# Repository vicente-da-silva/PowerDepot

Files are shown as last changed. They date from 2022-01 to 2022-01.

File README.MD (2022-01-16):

# Power Depot FJ Overland Build
## V1.0
The project started out with the goal of building a simple drawer system for my FJ. That simple goal turned into this Power Depot project! I may decide to split this project into 2 in the future as the Power Depot electronics evolve but for now the electrical and drawer system is presented as a single project.
Check out the detailed assembly document PowerDepotV1.pdf
It should be possible to easily create designs for other vehicles using the parts designed in this project.


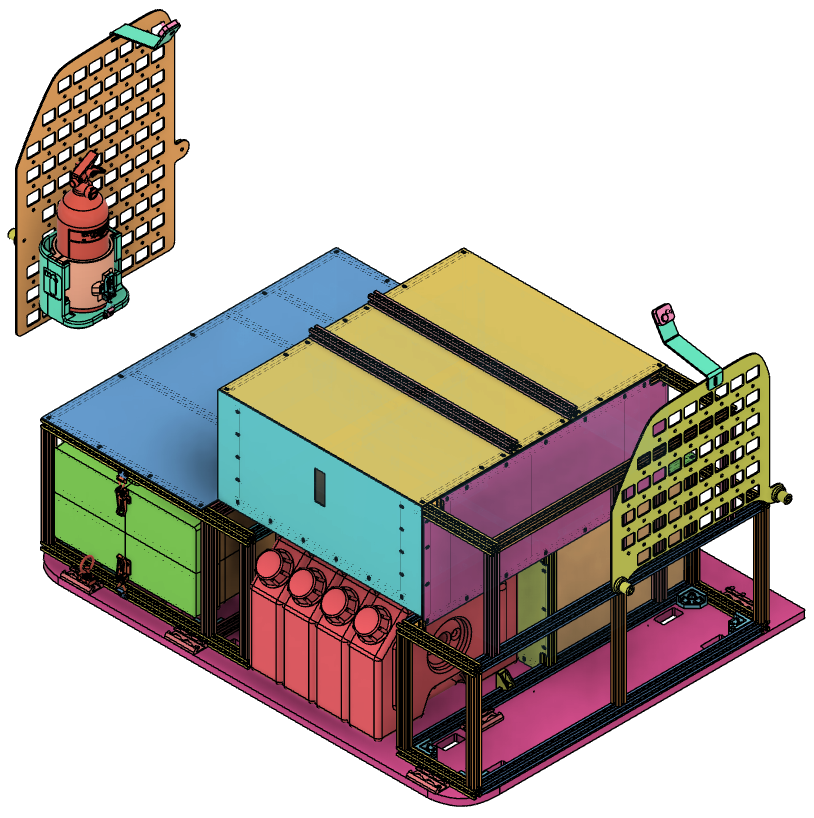
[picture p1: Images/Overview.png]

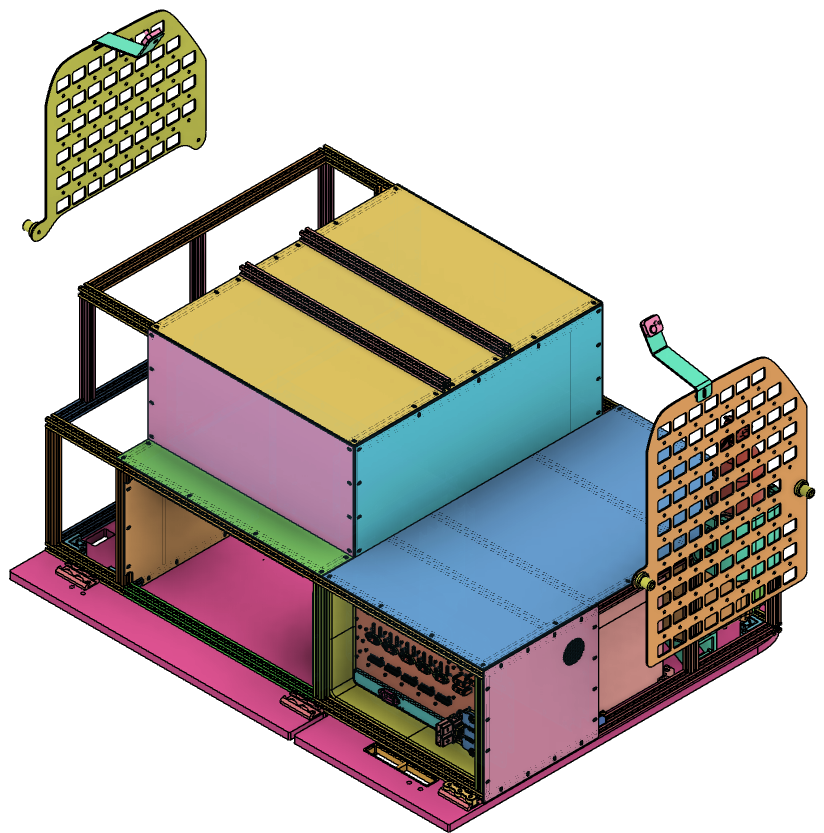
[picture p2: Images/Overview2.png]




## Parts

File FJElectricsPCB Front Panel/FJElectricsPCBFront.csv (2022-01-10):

Source: | C:\Users\vicen\OneDrive\Documents\Data\Code\FJElectricsPCB Front Panel\FJElectricsPCBFront.sch
Date: | 2021/04/24 10:04:37 AM
Tool: | Eeschema (5.1.8)-1
Generator: | C:\Program Files\KiCad\bin\scripting\plugins/bom_csv_grouped_by_value.py
Component Count: | 90
Individual Components:
Item | Qty | Reference(s) | Value | LibPart | Footprint | Datasheet
 |  | Fuse1 | LED | Device:LED | LED_THT:LED_D5.0mm | ~
 |  | Fuse2 | LED | Device:LED | LED_THT:LED_D5.0mm | ~
 |  | Fuse3 | LED | Device:LED | LED_THT:LED_D5.0mm | ~
 |  | Fuse4 | LED | Device:LED | LED_THT:LED_D5.0mm | ~
 |  | Fuse5 | LED | Device:LED | LED_THT:LED_D5.0mm | ~
 |  | Fuse6 | LED | Device:LED | LED_THT:LED_D5.0mm | ~
 |  | Fuse7 | LED | Device:LED | LED_THT:LED_D5.0mm | ~
 |  | Fuse8 | LED | Device:LED | LED_THT:LED_D5.0mm | ~
 |  | Fuse9 | LED | Device:LED | LED_THT:LED_D5.0mm | ~
 |  | Fuse10 | LED | Device:LED | LED_THT:LED_D5.0mm | ~
 |  | Fuse_1 | 30A | Device:Fuse | FJElectricsPCBCommon:FuseHolder20x5Fuse | ~
 |  | Fuse_2 | 30A | Device:Fuse | FJElectricsPCBCommon:FuseHolder20x5Fuse | ~
 |  | Fuse_3 | 30A | Device:Fuse | FJElectricsPCBCommon:FuseHolder20x5Fuse | ~
 |  | Fuse_4 | 30A | Device:Fuse | FJElectricsPCBCommon:FuseHolder20x5Fuse | ~
 |  | Fuse_5 | 30A | Device:Fuse | FJElectricsPCBCommon:FuseHolder20x5Fuse | ~
 |  | Fuse_6 | 30A | Device:Fuse | FJElectricsPCBCommon:FuseHolder20x5Fuse | ~
 |  | Fuse_7 | 30A | Device:Fuse | FJElectricsPCBCommon:FuseHolder20x5Fuse | ~
 |  | Fuse_8 | 30A | Device:Fuse | FJElectricsPCBCommon:FuseHolder20x5Fuse | ~
 |  | Fuse_9 | 30A | Device:Fuse | FJElectricsPCBCommon:FuseHolder20x5Fuse | ~
 |  | Fuse_10 | 30A | Device:Fuse | FJElectricsPCBCommon:FuseHolder20x5Fuse | ~
 |  | H1 | MountingHole | Mechanical:MountingHole | FJElectricsPCBCommon:NPTH_3mm_ID | ~
 |  | H3 | MountingHole | Mechanical:MountingHole | FJElectricsPCBCommon:NPTH_3mm_ID | ~
 |  | H4 | MountingHole | Mechanical:MountingHole | FJElectricsPCBCommon:NPTH_3mm_ID | ~
 |  | H6 | MountingHole | Mechanical:MountingHole | FJElectricsPCBCommon:NPTH_3mm_ID | ~
 |  | H7 | MountingHole | Mechanical:MountingHole | FJElectricsPCBCommon:NPTH_3mm_ID | ~
 |  | H10 | MountingHole | Mechanical:MountingHole | FJElectricsPCBCommon:NPTH_3mm_ID | ~
 |  | H11 | MountingHole | Mechanical:MountingHole | FJElectricsPCBCommon:NPTH_3mm_ID | ~
 |  | H12 | MountingHole | Mechanical:MountingHole | FJElectricsPCBCommon:NPTH_3mm_ID | ~
 |  | H14 | MountingHole | Mechanical:MountingHole | FJElectricsPCBCommon:NPTH_3mm_ID | ~
 |  | H15 | MountingHole | Mechanical:MountingHole | FJElectricsPCBCommon:NPTH_3mm_ID | ~
 |  | H16 | MountingHole | Mechanical:MountingHole | FJElectricsPCBCommon:NPTH_3mm_ID | ~
 |  | H21 | MountingHole | Mechanical:MountingHole | FJElectricsPCBCommon:NPTH_3mm_ID | ~
 |  | H23 | MountingHole | Mechanical:MountingHole | FJElectricsPCBCommon:NPTH_3mm_ID | ~
 |  | H24 | MountingHole | Mechanical:MountingHole | FJElectricsPCBCommon:NPTH_3mm_ID | ~
 |  | H26 | MountingHole | Mechanical:MountingHole | FJElectricsPCBCommon:NPTH_3mm_ID | ~
 |  | H27 | MountingHole | Mechanical:MountingHole | FJElectricsPCBCommon:NPTH_3mm_ID | ~
 |  | H29 | MountingHole | Mechanical:MountingHole | FJElectricsPCBCommon:NPTH_3mm_ID | ~
 |  | H31 | MountingHole | Mechanical:MountingHole | FJElectricsPCBCommon:NPTH_3mm_ID | ~
 |  | H33 | MountingHole | Mechanical:MountingHole | FJElectricsPCBCommon:NPTH_3mm_ID | ~
 |  | H34 | MountingHole | Mechanical:MountingHole | FJElectricsPCBCommon:NPTH_3mm_ID | ~
 |  | H36 | MountingHole | Mechanical:MountingHole | FJElectricsPCBCommon:NPTH_3mm_ID | ~
 |  | J3 | MEDIUM TB x2 | Connector_Generic:Conn_01x02 | FJElectricsPCBCommon:TerminalBlock_7.62_2x1 | ~
 |  | J4 | MEDIUM TB x2 | Connector_Generic:Conn_01x02 | FJElectricsPCBCommon:TerminalBlock_7.62_2x1 | ~
 |  | J6 | MEDIUM TB x2 | Connector_Generic:Conn_01x02 | FJElectricsPCBCommon:TerminalBlock_7.62_2x1 | ~
 |  | J8 | MEDIUM TB x2 | Connector_Generic:Conn_01x02 | FJElectricsPCBCommon:TerminalBlock_7.62_2x1 | ~
 |  | J9 | MEDIUM TB x2 | Connector_Generic:Conn_01x02 | FJElectricsPCBCommon:TerminalBlock_7.62_2x1 | ~
 |  | J14 | MEDIUM TB x2 | Connector_Generic:Conn_01x02 | FJElectricsPCBCommon:TerminalBlock_7.62_2x1 | ~
 |  | J15 | PP 2 WAY | Connector_Generic:Conn_01x02 | FJElectricsPCBCommon:PowerPole_15_45 | ~
 |  | J16 | PP 2 WAY | Connector_Generic:Conn_01x02 | FJElectricsPCBCommon:PowerPole_15_45 | ~
 |  | J17 | MEDIUM TB x2 | Connector_Generic:Conn_01x02 | FJElectricsPCBCommon:TerminalBlock_7.62_2x1 | ~
 |  | J18 | Conn_01x01 | Connector_Generic:Conn_01x01 | FJElectricsPCBCommon:TerminalM20_x1 | ~
 |  | J19 | PP 2 WAY | Connector_Generic:Conn_01x02 | FJElectricsPCBCommon:PowerPole_15_45 | ~
 |  | J20 | MEDIUM TB x2 | Connector_Generic:Conn_01x02 | FJElectricsPCBCommon:TerminalBlock_7.62_2x1 | ~
 |  | J22 | PP 2 WAY | Connector_Generic:Conn_01x02 | FJElectricsPCBCommon:PowerPole_15_45 | ~
 |  | J24 | MEDIUM TB x2 | Connector_Generic:Conn_01x02 | FJElectricsPCBCommon:TerminalBlock_7.62_2x1 | ~
 |  | J25 | PP 2 WAY | Connector_Generic:Conn_01x02 | FJElectricsPCBCommon:PowerPole_15_45 | ~
 |  | J26 | MEDIUM TB x2 | Connector_Generic:Conn_01x02 | FJElectricsPCBCommon:TerminalBlock_7.62_2x1 | ~
 |  | J27 | MEDIUM TB x2 | Connector_Generic:Conn_01x02 | FJElectricsPCBCommon:TerminalBlock_7.62_2x1 | ~
 |  | J28 | PP 2 WAY | Connector_Generic:Conn_01x02 | FJElectricsPCBCommon:PowerPole_15_45 | ~
 |  | J29 | PP 2 WAY | Connector_Generic:Conn_01x02 | FJElectricsPCBCommon:PowerPole_15_45 | ~
 |  | J30 | PP 2 WAY | Connector_Generic:Conn_01x02 | FJElectricsPCBCommon:PowerPole_15_45 | ~
 |  | J31 | PP 2 WAY | Connector_Generic:Conn_01x02 | FJElectricsPCBCommon:PowerPole_15_45 | ~
 |  | J32 | Jumper_Bolt | FJPCBComponentsCommon:Jumper_Bolt | FJElectricsPCBCommon:ScrewM4Jumper
 |  | J33 | Jumper_Bolt | FJPCBComponentsCommon:Jumper_Bolt | FJElectricsPCBCommon:ScrewM4Jumper
 |  | J34 | Jumper_Bolt | FJPCBComponentsCommon:Jumper_Bolt | FJElectricsPCBCommon:ScrewM4Jumper
 |  | J35 | PP 2 WAY | Connector_Generic:Conn_01x02 | FJElectricsPCBCommon:PowerPole_15_45 | ~
 |  | J36 | PP 2 WAY | Connector_Generic:Conn_01x02 | FJElectricsPCBCommon:PowerPole_15_45 | ~
 |  | J37 | Jumper_Bolt | FJPCBComponentsCommon:Jumper_Bolt | FJElectricsPCBCommon:ScrewM4Jumper
 |  | J38 | Jumper_Bolt | FJPCBComponentsCommon:Jumper_Bolt | FJElectricsPCBCommon:ScrewM4Jumper
 |  | J39 | Conn_01x01 | Connector_Generic:Conn_01x01 | FJElectricsPCBCommon:TerminalM20_x1 | ~
 |  | K1 | CB1-R-12V | FJPCBComponentsCommon:CB1-R-12V | FJElectricsPCBCommon:MINI_ISO_RELAY_SOCKET | https://www.panasonic-electric-works.com/pew/es/downloads/ds_dw_hl_en.pdf
 |  | K2 | CB1-R-12V | FJPCBComponentsCommon:CB1-R-12V | FJElectricsPCBCommon:MINI_ISO_RELAY_SOCKET | https://www.panasonic-electric-works.com/pew/es/downloads/ds_dw_hl_en.pdf
 |  | K3 | CB1-R-12V | FJPCBComponentsCommon:CB1-R-12V | FJElectricsPCBCommon:MINI_ISO_RELAY_SOCKET | https://www.panasonic-electric-works.com/pew/es/downloads/ds_dw_hl_en.pdf
 |  | K4 | CB1-R-12V | FJPCBComponentsCommon:CB1-R-12V | FJElectricsPCBCommon:MINI_ISO_RELAY_SOCKET | https://www.panasonic-electric-works.com/pew/es/downloads/ds_dw_hl_en.pdf
 |  | K5 | CB1-R-12V | FJPCBComponentsCommon:CB1-R-12V | FJElectricsPCBCommon:MINI_ISO_RELAY_SOCKET | https://www.panasonic-electric-works.com/pew/es/downloads/ds_dw_hl_en.pdf
 |  | R1 | 600 | Device:R_US | Resistor_THT:R_Axial_DIN0207_L6.3mm_D2.5mm_P10.16mm_Horizontal | ~
 |  | R2 | 600 | Device:R_US | Resistor_THT:R_Axial_DIN0207_L6.3mm_D2.5mm_P10.16mm_Horizontal | ~
 |  | R3 | 600 | Device:R_US | Resistor_THT:R_Axial_DIN0207_L6.3mm_D2.5mm_P10.16mm_Horizontal | ~
 |  | R4 | 600 | Device:R_US | Resistor_THT:R_Axial_DIN0207_L6.3mm_D2.5mm_P10.16mm_Horizontal | ~
 |  | R5 | 600 | Device:R_US | Resistor_THT:R_Axial_DIN0207_L6.3mm_D2.5mm_P10.16mm_Horizontal | ~
 |  | R6 | 600 | Device:R_US | Resistor_THT:R_Axial_DIN0207_L6.3mm_D2.5mm_P10.16mm_Horizontal | ~
 |  | R7 | 600 | Device:R_US | Resistor_THT:R_Axial_DIN0207_L6.3mm_D2.5mm_P10.16mm_Horizontal | ~
 |  | R8 | 600 | Device:R_US | Resistor_THT:R_Axial_DIN0207_L6.3mm_D2.5mm_P10.16mm_Horizontal | ~
 |  | R9 | 600 | Device:R_US | Resistor_THT:R_Axial_DIN0207_L6.3mm_D2.5mm_P10.16mm_Horizontal | ~
 |  | R10 | 600 | Device:R_US | Resistor_THT:R_Axial_DIN0207_L6.3mm_D2.5mm_P10.16mm_Horizontal | ~
 |  | SW1 | SW_SPST | Switch:SW_SPST | FJElectricsPCBCommon:SwitchMount | ~
 |  | SW2 | SW_SPST | Switch:SW_SPST | FJElectricsPCBCommon:SwitchMount | ~
 |  | SW3 | SW_SPST | Switch:SW_SPST | FJElectricsPCBCommon:SwitchMount | ~
 |  | SW4 | SW_SPST | Switch:SW_SPST | FJElectricsPCBCommon:SwitchMount | ~
 |  | SW5 | SW_SPST | Switch:SW_SPST | FJElectricsPCBCommon:SwitchMount | ~
Collated Components:
Item | Qty | Reference(s) | Value | LibPart | Footprint | Datasheet
1 | 10 | Fuse1, Fuse2, Fuse3, Fuse4, Fuse5, Fuse6, Fuse7, Fuse8, Fuse9, Fuse10 | LED | Device:LED | LED_THT:LED_D5.0mm | ~
2 | 10 | Fuse_1, Fuse_2, Fuse_3, Fuse_4, Fuse_5, Fuse_6, Fuse_7, Fuse_8, Fuse_9, Fuse_10 | 30A | Device:Fuse | FJElectricsPCBCommon:FuseHolder20x5Fuse | ~
3 | 21 | H1, H3, H4, H6, H7, H10, H11, H12, H14, H15, H16, H21, H23, H24, H26, H27, H29, H31, H33, H34, H36 | MountingHole | Mechanical:MountingHole | FJElectricsPCBCommon:NPTH_3mm_ID | ~
4 | 11 | J3, J4, J6, J8, J9, J14, J17, J20, J24, J26, J27 | MEDIUM TB x2 | Connector_Generic:Conn_01x02 | FJElectricsPCBCommon:TerminalBlock_7.62_2x1 | ~
5 | 11 | J15, J16, J19, J22, J25, J28, J29, J30, J31, J35, J36 | PP 2 WAY | Connector_Generic:Conn_01x02 | FJElectricsPCBCommon:PowerPole_15_45 | ~
6 | 2 | J18, J39 | Conn_01x01 | Connector_Generic:Conn_01x01 | FJElectricsPCBCommon:TerminalM20_x1 | ~
7 | 5 | J32, J33, J34, J37, J38 | Jumper_Bolt | FJPCBComponentsCommon:Jumper_Bolt | FJElectricsPCBCommon:ScrewM4Jumper
8 | 5 | K1, K2, K3, K4, K5 | CB1-R-12V | FJPCBComponentsCommon:CB1-R-12V | FJElectricsPCBCommon:MINI_ISO_RELAY_SOCKET | https://www.panasonic-electric-works.com/pew/es/downloads/ds_dw_hl_en.pdf
9 | 10 | R1, R2, R3, R4, R5, R6, R7, R8, R9, R10 | 600 | Device:R_US | Resistor_THT:R_Axial_DIN0207_L6.3mm_D2.5mm_P10.16mm_Horizontal | ~
10 | 5 | SW1, SW2, SW3, SW4, SW5 | SW_SPST | Switch:SW_SPST | FJElectricsPCBCommon:SwitchMount | ~

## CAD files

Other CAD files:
FJElectricsPCB Back Panel/FJElectricsPCBBack.step
FJElectricsPCB Front Panel/FJElectricsPCBFront.step
FJMechanical/FJDrawerExtrusionV2 v261.step
FJElectricsPCB Common/3d packages/M10 hole in a M20 95 Lug.step
FJElectricsPCB Common/3d packages/SB 120.step
FJElectricsPCB Common/3d packages/SB 50.step
FJElectricsPCB Common/3d packages/TerminalMount.step
FJElectricsPCB Common/3d packages/MegaFuse.step
FJElectricsPCB Common/3d packages/Maxi Fuse.step
FJElectricsPCB Common/3d packages/PCB Fuse Reguar Mount.step
FJElectricsPCB Common/3d packages/RegularFuse.step
FJElectricsPCB Common/3d packages/2-1904045-4 Relay Conn.step
FJElectricsPCB Common/3d packages/RelaySocket.step
FJElectricsPCB Common/3d packages/TB005-762-02P_Black - S.step
FJElectricsPCB Common/3d packages/MegaMount.step
FJElectricsPCB Common/3d packages/PCB Fuse Maxi Mount.step
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

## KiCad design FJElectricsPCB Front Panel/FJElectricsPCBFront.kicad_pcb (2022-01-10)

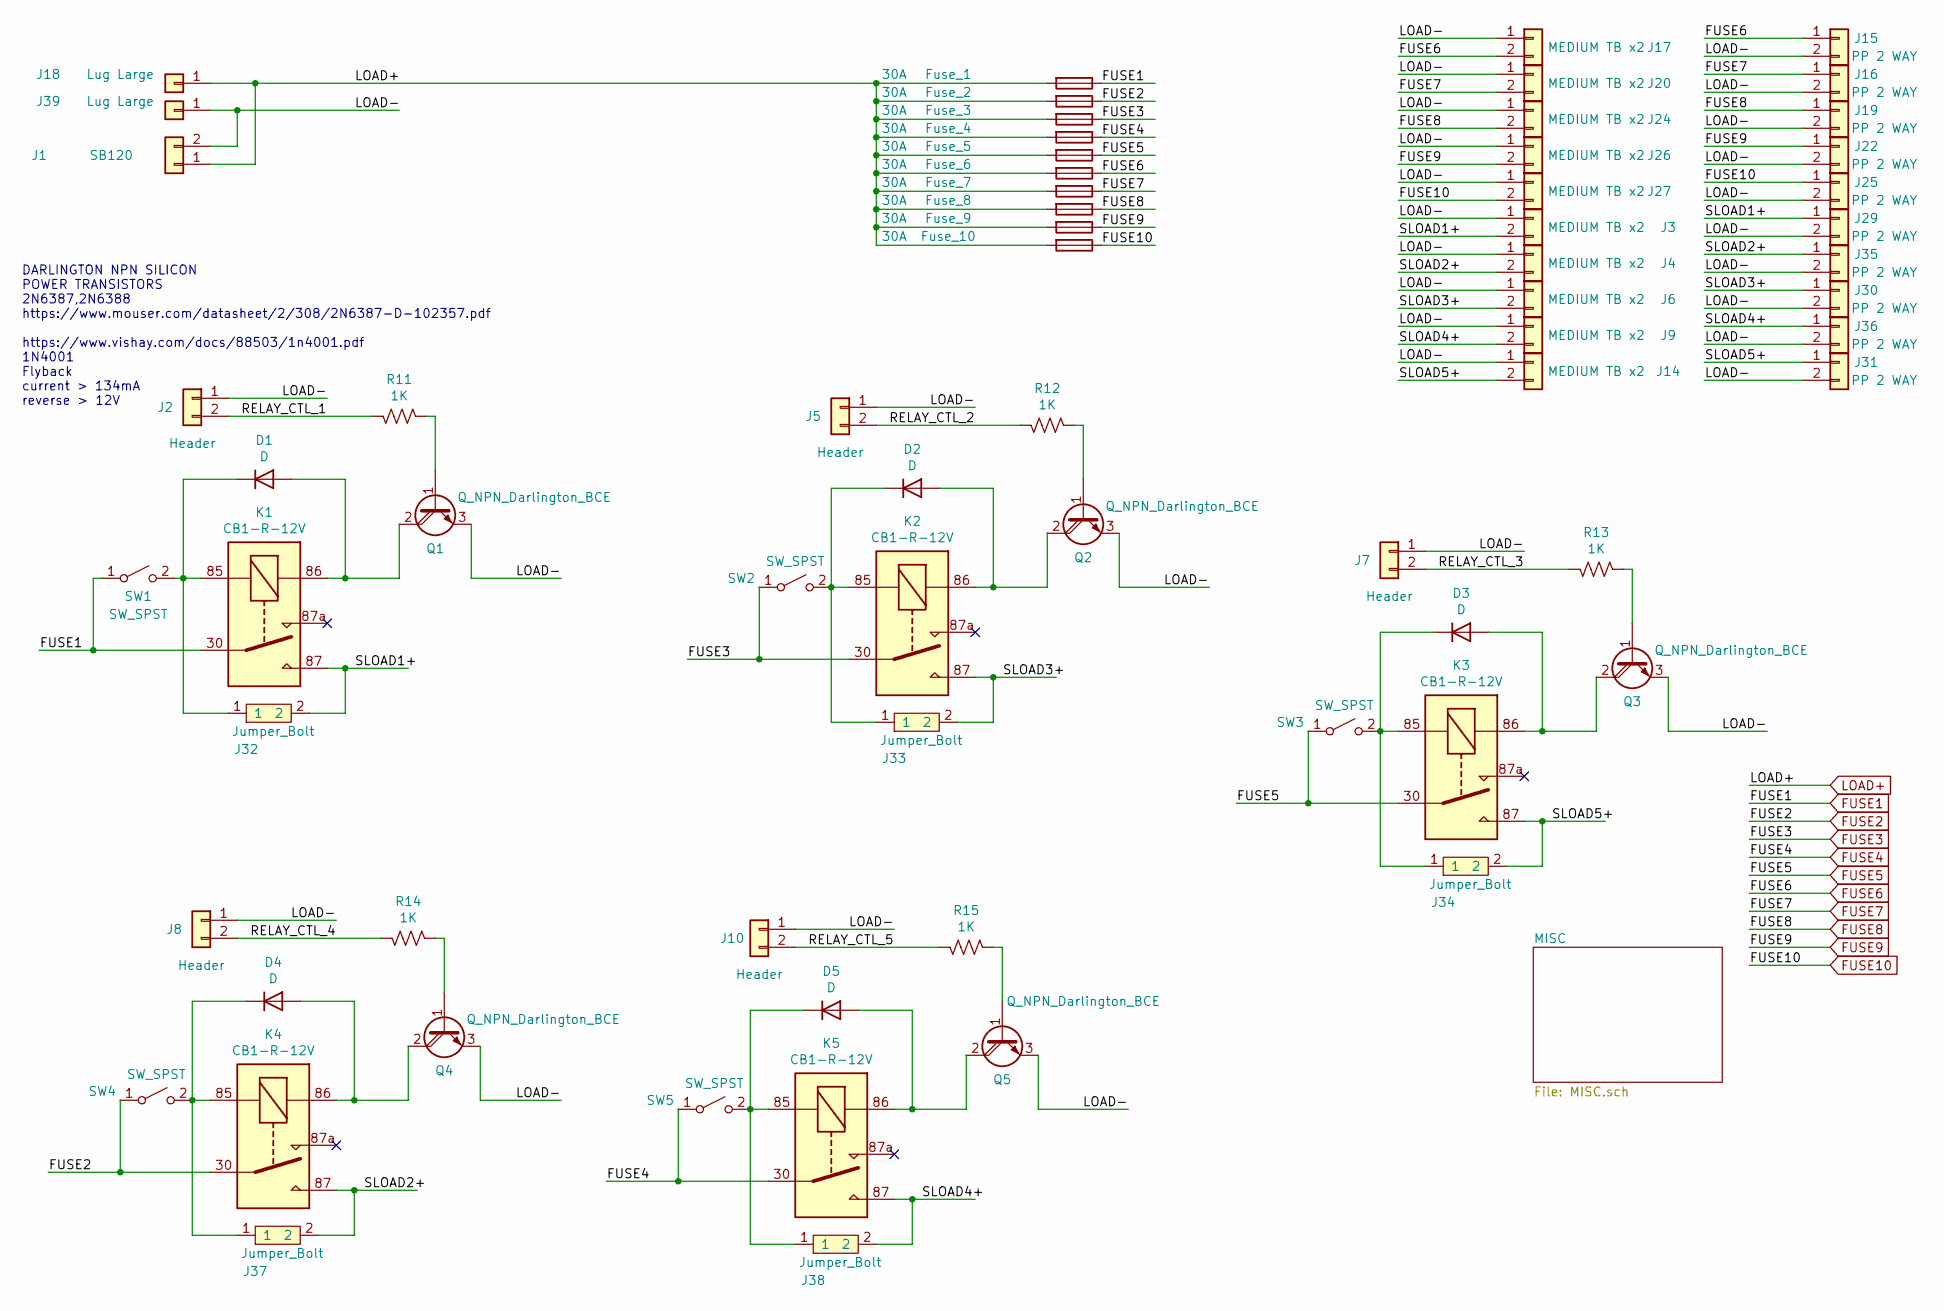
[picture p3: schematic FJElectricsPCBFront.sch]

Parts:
D1, D2, D3, D4, D5: D; D_DO-41_SOD81_P10.16mm_Horizontal
Fuse_1, Fuse_2, Fuse_3, Fuse_4, Fuse_5, Fuse_6, Fuse_7, Fuse_8, Fuse_9, Fuse_10: 30A; FuseHolder20x5Fuse
J1: SB120; SA120
J2, J5, J7, J8, J10: Header; TerminalBlock_Phoenix_MPT-0,5-2-2.54_1x02_P2.54mm_Horizontal
J3, J4, J6, J9, J14, J17, J20, J24, J26, J27: MEDIUM TB x2; TerminalBlock_7.62_2x1
J15, J16, J19, J22, J25, J29, J30, J31, J35, J36: PP 2 WAY; PowerPole_15_45
J18, J39: Lug Large; TerminalM20_x1
J32, J33, J34, J37, J38: Jumper_Bolt; ScrewM4Jumper
K1, K2, K3, K4, K5: CB1-R-12V; Relay_PCB_Socket_V23333
Q1, Q2, Q3, Q4, Q5: Q_NPN_Darlington_BCE; TO-220-3_Vertical
R11, R12, R13, R14, R15: 1K; R_Axial_DIN0207_L6.3mm_D2.5mm_P10.16mm_Horizontal
SW1, SW2, SW3, SW4, SW5: SW_SPST; SwitchMount

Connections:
/LOAD-: J1.2, J2.1, J3.1, J4.1, J5.1, J6.1, J7.1, J8.1, J9.1, J10.1, J14.1, J15.2, J16.2, J17.1, J19.2, J20.1, J22.2, J24.1, J25.2, J26.1, J27.1, J29.2, J30.2, J31.2, J35.2, J36.2, J39.1, Q1.3 (E), Q2.3 (E), Q3.3 (E), Q4.3 (E), Q5.3 (E)
/RELAY_CTL_1: J2.2, R11.1
/RELAY_CTL_2: J5.2, R12.1
/RELAY_CTL_3: J7.2, R13.1
/RELAY_CTL_4: J8.2, R14.1
/RELAY_CTL_5: J10.2, R15.1
/SLOAD1+: J3.2, J29.1, J32.2, K1.87
/SLOAD2+: J4.2, J35.1, J37.2, K4.87
/SLOAD3+: J6.2, J30.1, J33.2, K2.87
/SLOAD4+: J9.2, J36.1, J38.2, K5.87
/SLOAD5+: J14.2, J31.1, J34.2, K3.87
FUSE1: Fuse_1.1, K1.30, SW1.1 (A); also elsewhere on the board
FUSE2: Fuse_2.1, K4.30, SW4.1 (A); also elsewhere on the board
FUSE3: Fuse_3.1, K2.30, SW2.1 (A); also elsewhere on the board
FUSE4: Fuse_4.1, K5.30, SW5.1 (A); also elsewhere on the board
FUSE5: Fuse_5.1, K3.30, SW3.1 (A); also elsewhere on the board
FUSE6: Fuse_6.1, J15.1, J17.2; also elsewhere on the board
FUSE7: Fuse_7.1, J16.1, J20.2; also elsewhere on the board
FUSE8: Fuse_8.1, J19.1, J24.2; also elsewhere on the board
FUSE9: Fuse_9.1, J22.1, J26.2; also elsewhere on the board
FUSE10: Fuse_10.1, J25.1, J27.2; also elsewhere on the board
LOAD+: Fuse_1.2, Fuse_2.2, Fuse_3.2, Fuse_4.2, Fuse_5.2, Fuse_6.2, Fuse_7.2, Fuse_8.2, Fuse_9.2, Fuse_10.2, J1.1, J18.1; also elsewhere on the board
unnamed: D1.1 (K), J32.1, K1.85, SW1.2 (B)
unnamed: D1.2 (A), K1.86, Q1.2 (C)
unnamed: D2.1 (K), J33.1, K2.85, SW2.2 (B)
unnamed: D2.2 (A), K2.86, Q2.2 (C)
unnamed: D3.1 (K), J34.1, K3.85, SW3.2 (B)
unnamed: D3.2 (A), K3.86, Q3.2 (C)
unnamed: D4.1 (K), J37.1, K4.85, SW4.2 (B)
unnamed: D4.2 (A), K4.86, Q4.2 (C)
unnamed: D5.1 (K), J38.1, K5.85, SW5.2 (B)
unnamed: D5.2 (A), K5.86, Q5.2 (C)
unnamed: Q1.1 (B), R11.2
unnamed: Q2.1 (B), R12.2
unnamed: Q3.1 (B), R13.2
unnamed: Q4.1 (B), R14.2
unnamed: Q5.1 (B), R15.2

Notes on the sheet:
DARLINGTON NPN SILICON POWER TRANSISTORS 2N6387,2N6388 https://www.mouser.com/datasheet/2/308/2N6387-D-102357.pdf https://www.vishay.com/docs/88503/1n4001.pdf 1N4001 Flyback current > 134mA reverse > 12V

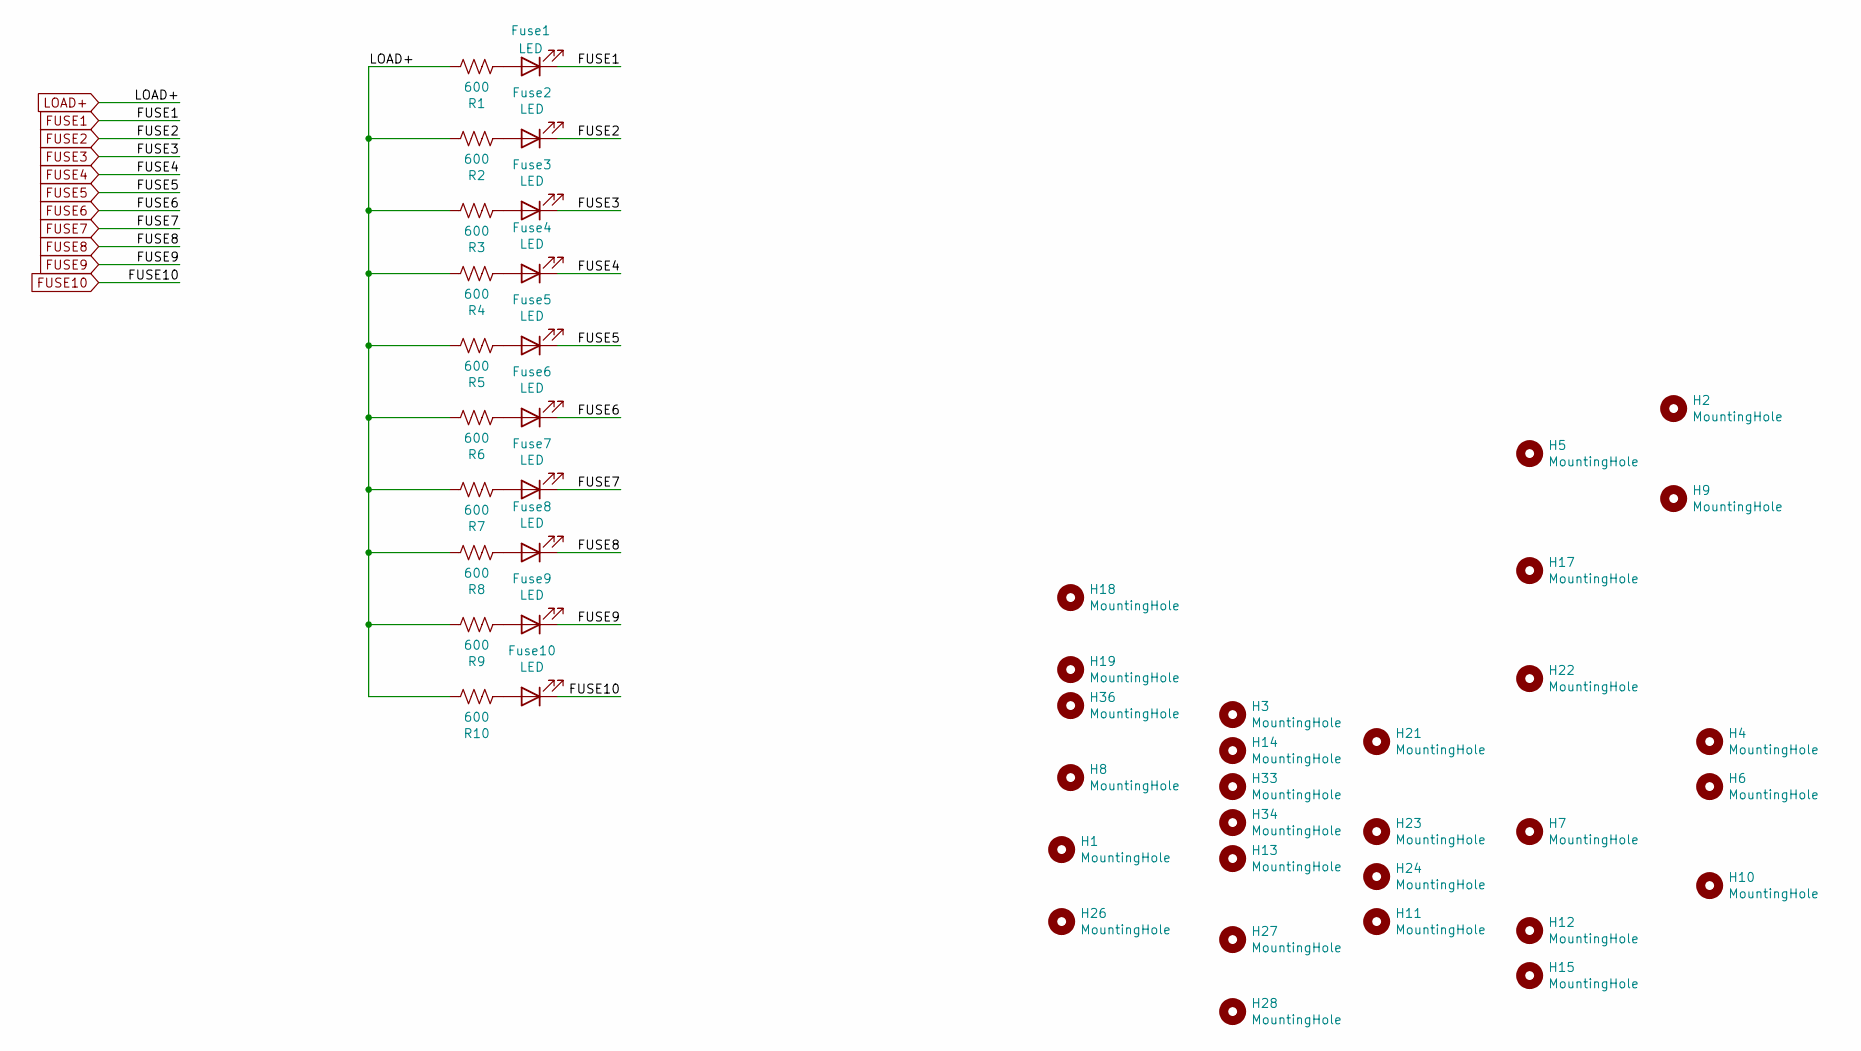
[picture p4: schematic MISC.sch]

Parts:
Fuse1, Fuse2, Fuse3, Fuse4, Fuse5, Fuse6, Fuse7, Fuse8, Fuse9, Fuse10: LED; LED_D5.0mm
H1, H2, H3, H4, H5, H6, H7, H8, H9, H10, H11, H12, H13, H14, H15, H17, H18, H19, H21, H22, H23, H24, H26, H27, H28, H33, H34, H36: MountingHole; NPTH_3mm_ID
R1, R2, R3, R4, R5, R6, R7, R8, R9, R10: 600; R_Axial_DIN0207_L6.3mm_D2.5mm_P10.16mm_Horizontal

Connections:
FUSE1: Fuse1.1 (K); also elsewhere on the board
FUSE2: Fuse2.1 (K); also elsewhere on the board
FUSE3: Fuse3.1 (K); also elsewhere on the board
FUSE4: Fuse4.1 (K); also elsewhere on the board
FUSE5: Fuse5.1 (K); also elsewhere on the board
FUSE6: Fuse6.1 (K); also elsewhere on the board
FUSE7: Fuse7.1 (K); also elsewhere on the board
FUSE8: Fuse8.1 (K); also elsewhere on the board
FUSE9: Fuse9.1 (K); also elsewhere on the board
FUSE10: Fuse10.1 (K); also elsewhere on the board
LOAD+: R1.1, R2.1, R3.1, R4.1, R5.1, R6.1, R7.1, R8.1, R9.1, R10.1; also elsewhere on the board
unnamed: Fuse1.2 (A), R1.2
unnamed: Fuse2.2 (A), R2.2
unnamed: Fuse3.2 (A), R3.2
unnamed: Fuse4.2 (A), R4.2
unnamed: Fuse5.2 (A), R5.2
unnamed: Fuse6.2 (A), R6.2
unnamed: Fuse7.2 (A), R7.2
unnamed: Fuse8.2 (A), R8.2
unnamed: Fuse9.2 (A), R9.2
unnamed: Fuse10.2 (A), R10.2

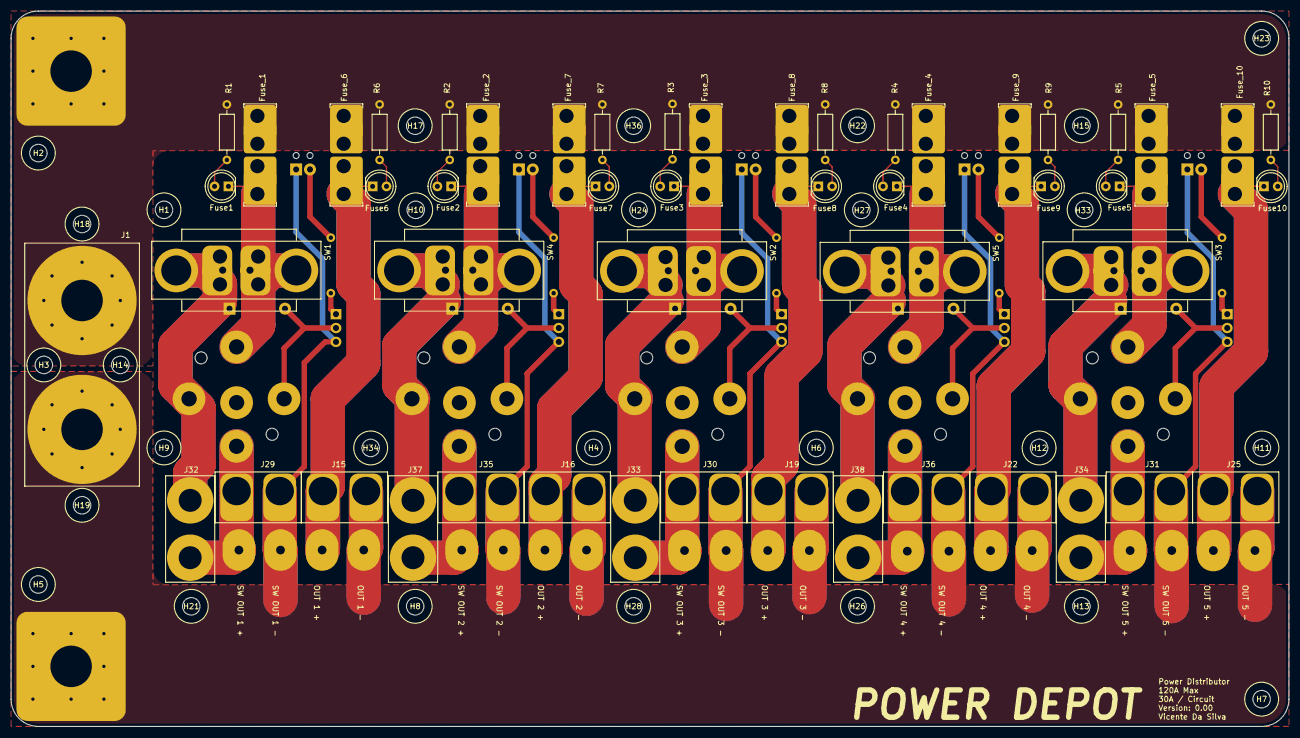
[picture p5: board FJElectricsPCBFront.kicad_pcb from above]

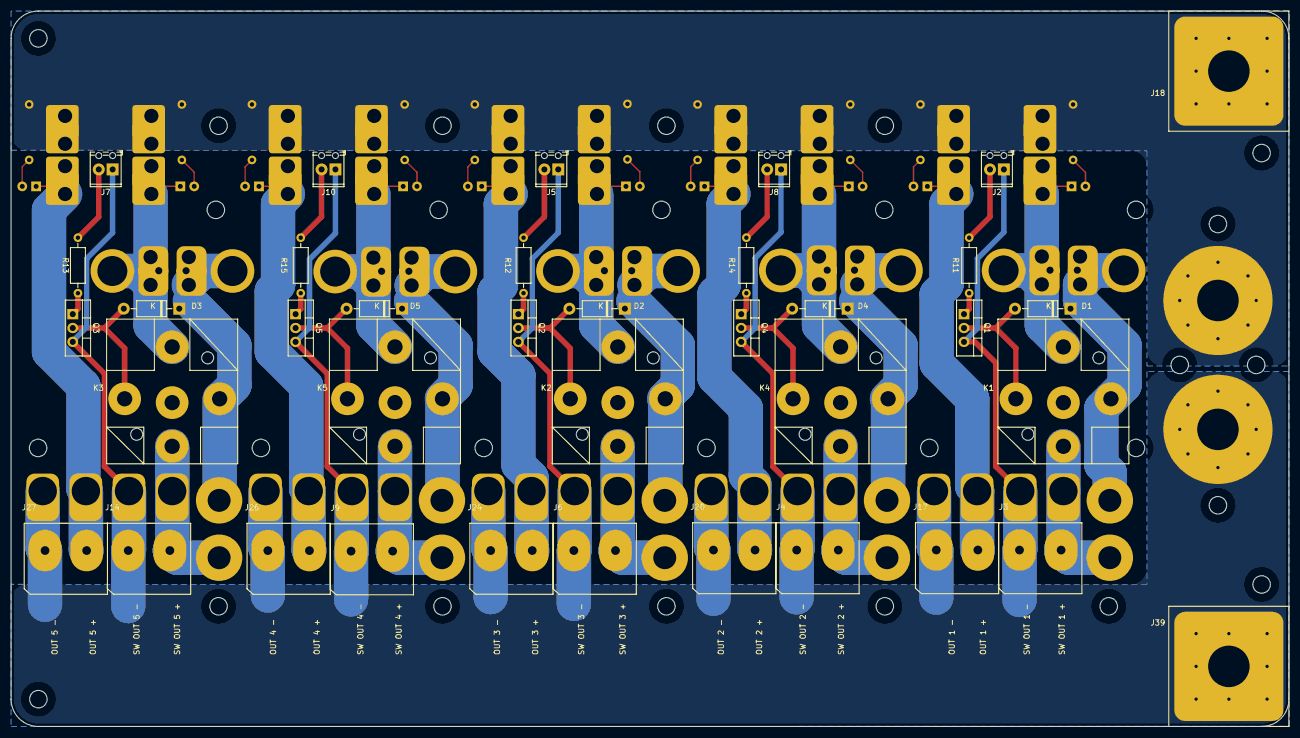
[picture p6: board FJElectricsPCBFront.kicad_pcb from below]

Board: 2 copper layers, 234.0 x 131.0 mm, 116 parts (37 on the bottom side), 47 nets.

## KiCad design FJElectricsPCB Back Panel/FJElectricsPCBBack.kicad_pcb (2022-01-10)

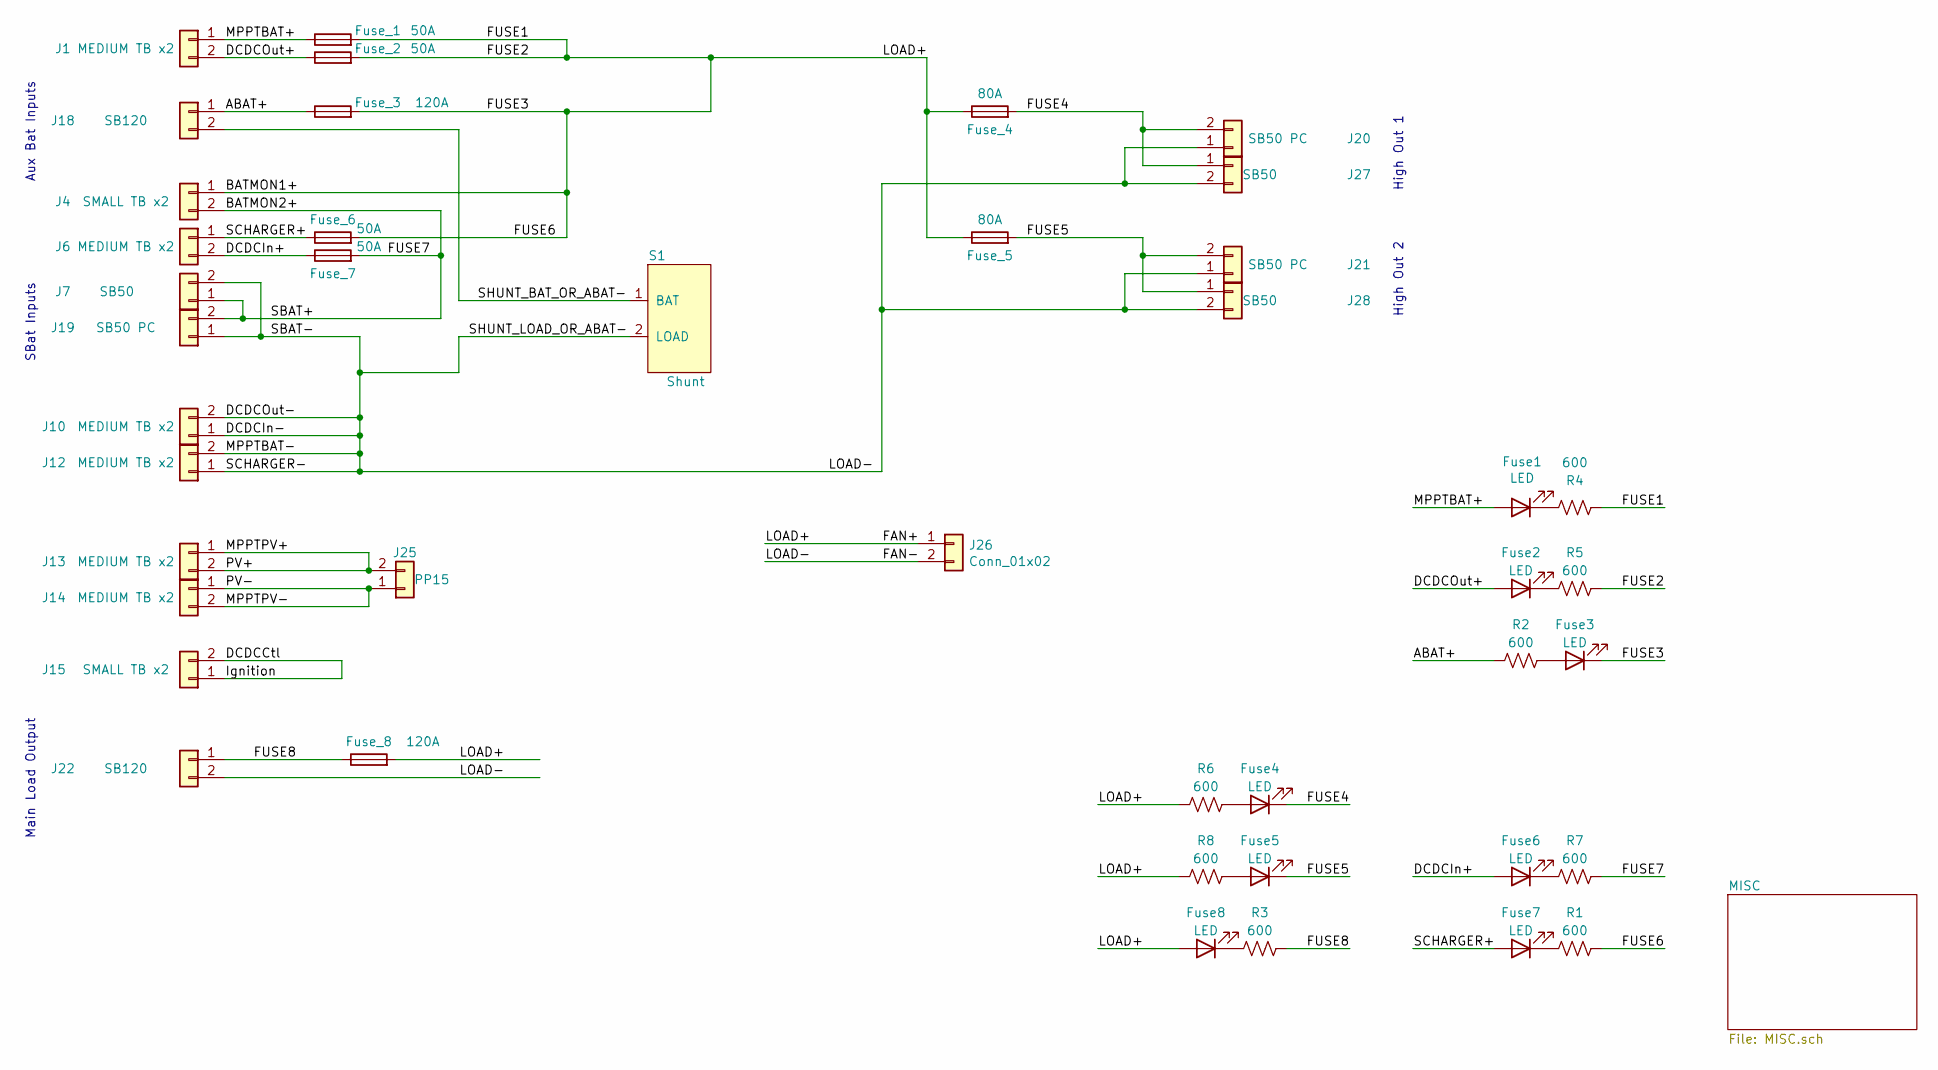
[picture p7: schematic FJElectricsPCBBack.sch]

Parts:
Fuse1, Fuse2, Fuse3, Fuse4, Fuse5, Fuse6, Fuse7, Fuse8: LED; LED_D5.0mm
Fuse_1, Fuse_2, Fuse_6, Fuse_7: 50A; FuseHolderMaxi
Fuse_3, Fuse_8: 120A; FuseHolderMaxiWithMega
Fuse_4, Fuse_5: 80A; FuseHolderMaxi
J1, J6, J10, J12, J13, J14: MEDIUM TB x2; TerminalBlock_7.62_2x1
J4, J15: SMALL TB x2; TerminalBlock_5_2x1
J7, J27, J28: SB50; SA50_2
J18, J22: SB120; SA120
J19, J20, J21: SB50 PC; SA50
J25: PP15; PowerPole_15_45
J26: Conn_01x02; PinHeader_1x02_P2.54mm_Vertical
R1, R2, R3, R4, R5, R6, R7, R8: 600; R_Axial_DIN0207_L6.3mm_D2.5mm_P10.16mm_Horizontal
S1: Shunt

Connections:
/ABAT+: Fuse_3.1, J18.1, R2.1
/BATMON1+: Fuse3.1 (K), Fuse8.2 (A), Fuse_1.2, Fuse_2.2, Fuse_3.2, Fuse_4.1, Fuse_5.1, Fuse_6.2, Fuse_8.2, J4.1, J26.1, R1.2, R4.2, R5.2, R6.1, R8.1
/BATMON2+: Fuse_7.2, J4.2, J7.1, J19.2, R7.2
/DCDCCtl: J15.1, J15.2
/DCDCIn+: Fuse6.2 (A), Fuse_7.1, J6.2
/DCDCIn-: J7.2, J10.1, J10.2, J12.1, J12.2, J19.1, J20.1, J21.1, J22.2, J26.2, J27.2, J28.2, S1.2 (LOAD)
/DCDCOut+: Fuse2.2 (A), Fuse_2.1, J1.2
/FUSE4: Fuse4.1 (K), Fuse_4.2, J20.2, J27.1
/FUSE5: Fuse5.1 (K), Fuse_5.2, J21.2, J28.1
/FUSE8: Fuse_8.1, J22.1, R3.2
/MPPTBAT+: Fuse1.2 (A), Fuse_1.1, J1.1
/MPPTPV+: J13.1, J13.2, J25.2
/MPPTPV-: J14.1, J14.2, J25.1
/SCHARGER+: Fuse7.2 (A), Fuse_6.1, J6.1
/SHUNT_BAT_OR_ABAT-: J18.2, S1.1 (BAT)
unnamed: Fuse1.1 (K), R4.1
unnamed: Fuse2.1 (K), R5.1
unnamed: Fuse3.2 (A), R2.2
unnamed: Fuse4.2 (A), R6.2
unnamed: Fuse5.2 (A), R8.2
unnamed: Fuse6.1 (K), R7.1
unnamed: Fuse7.1 (K), R1.1
unnamed: Fuse8.1 (K), R3.1

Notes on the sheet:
SBat Inputs
Aux Bat Inputs
Main Load Output
High Out 1
High Out 2

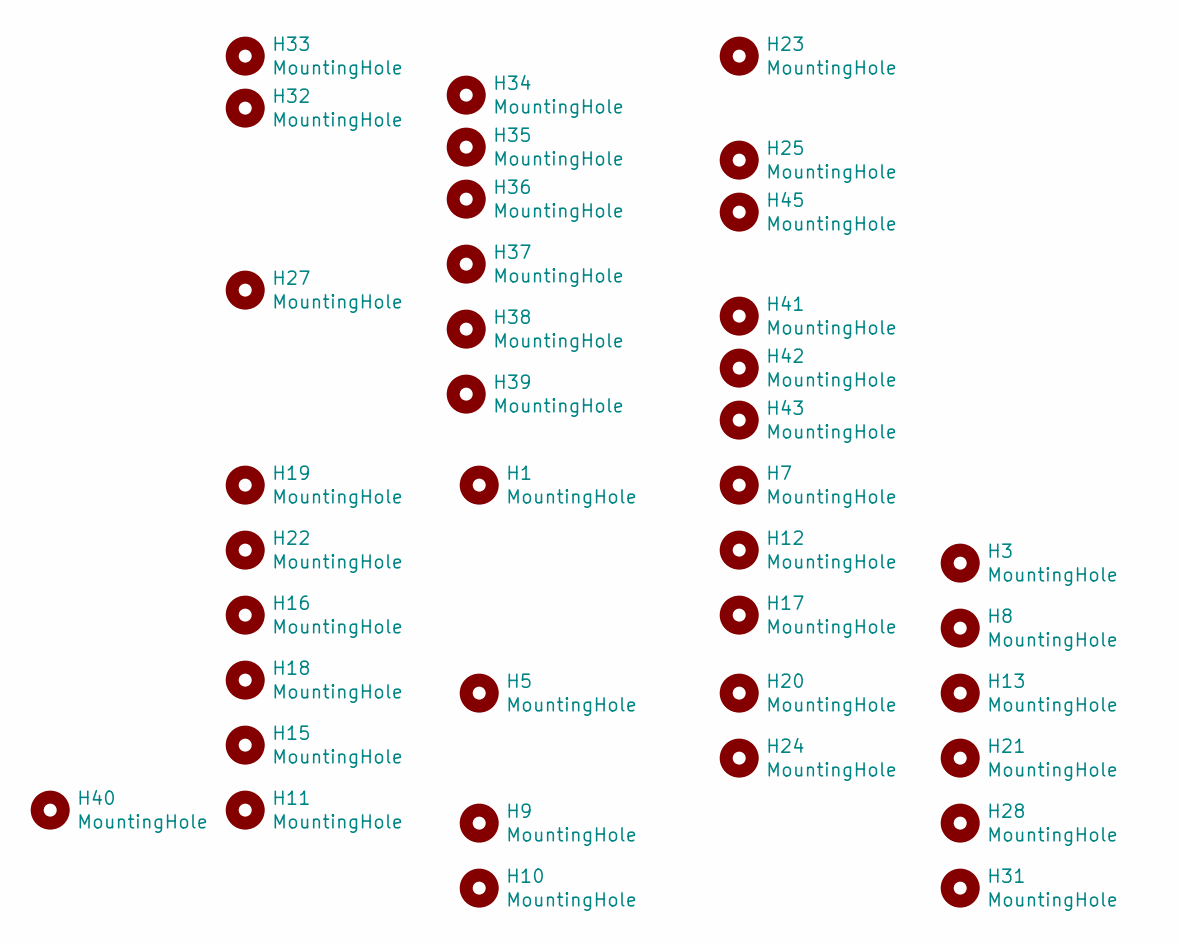
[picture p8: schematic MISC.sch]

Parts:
H1, H3, H5, H7, H8, H9, H10, H11, H12, H13, H15, H16, H17, H18, H19, H20, H21, H22, H23, H24, H25, H27, H28, H31, H32, H33, H34, H35, H36, H37, H38, H39, H40, H41, H42, H43, H45: MountingHole; NPTH_3mm_ID

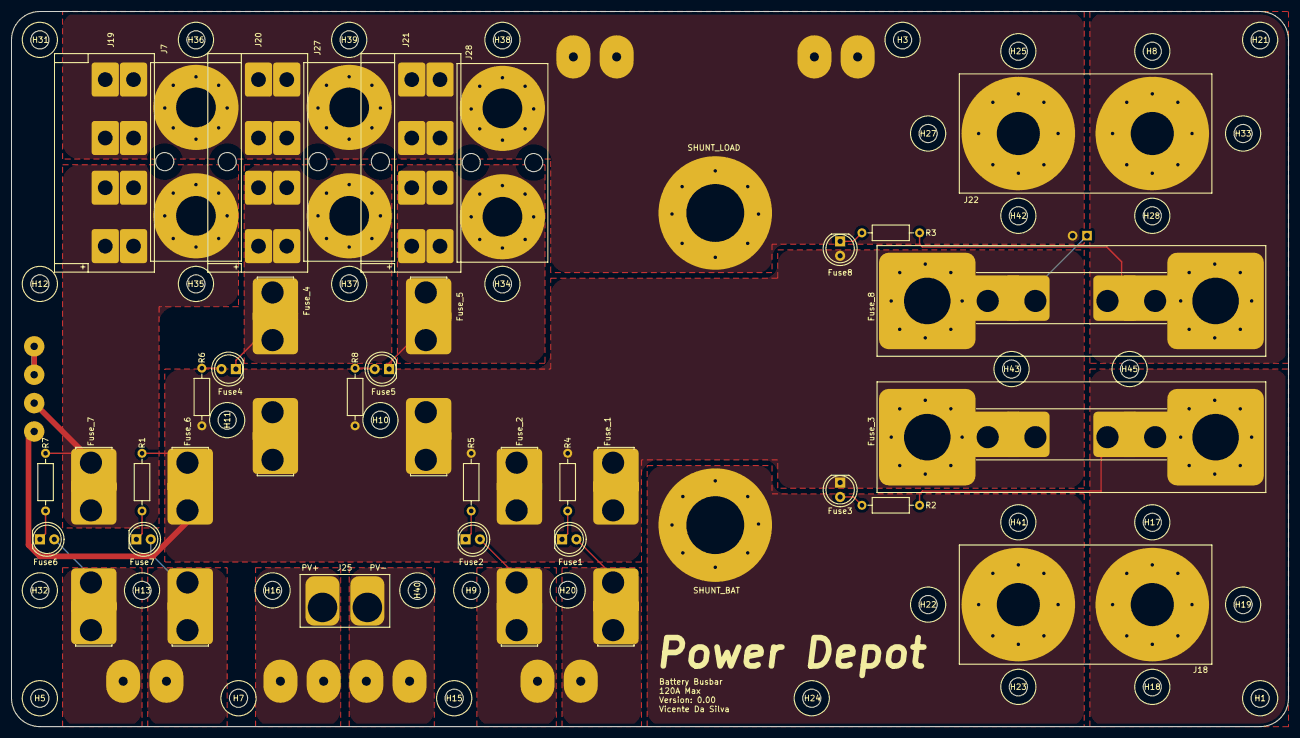
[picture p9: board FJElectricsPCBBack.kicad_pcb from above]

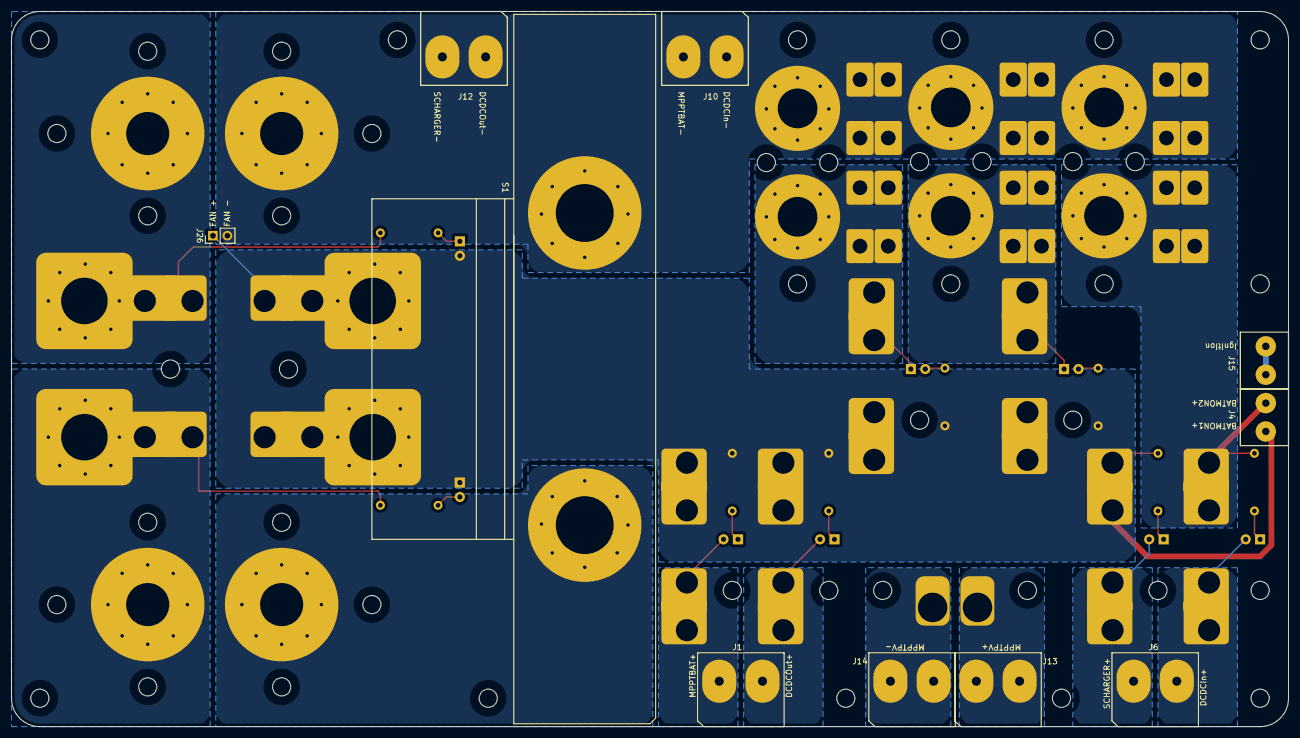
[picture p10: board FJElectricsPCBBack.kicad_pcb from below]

Board: 2 copper layers, 225.0 x 126.0 mm, 80 parts (10 on the bottom side), 23 nets.
